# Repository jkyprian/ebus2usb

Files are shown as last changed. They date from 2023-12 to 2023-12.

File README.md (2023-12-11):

# ebus2usb - 1TE DIN Rail eBUS to USB Type-C Interface

eBUS is a serial 2-wire serial data-bus, often used in heating, solar energy, and other building automation systems. This project provides an interface to access an eBUS via USB.
It uses a series transistor regulator circuit with a low IZT zener diode to extract the operating voltage from the eBUS, an ADuM1201 for the galvanic isolation, and a STM32 microcontroller for the UART to USB conversion.
Power consumption on the eBUS side is between 475uA (eBUS low/8V) and 750uA (eBUS idle high/24V), making the interface qualify as a class 0 device with respect to the eBUS specification.
It has been designed to fit into an [CNMB/1/2](https://www.camdenboss.com/camden-boss/cnmb12-din-rail-module-box%2c-polycarbonate-enclosure%2c-industrial-iot-electronics-housing/c-23/p-18541) 1TE DIN rail enclosure by CAMDENBOSS. The interface is intended to be used with [ebusd](https://github.com/john30/ebusd/). Note that the firmware is currently just a proof-of-concept and only implements a basic uart to USB bridge. Support for the ebusd enhanced protocol is planned for the near future.

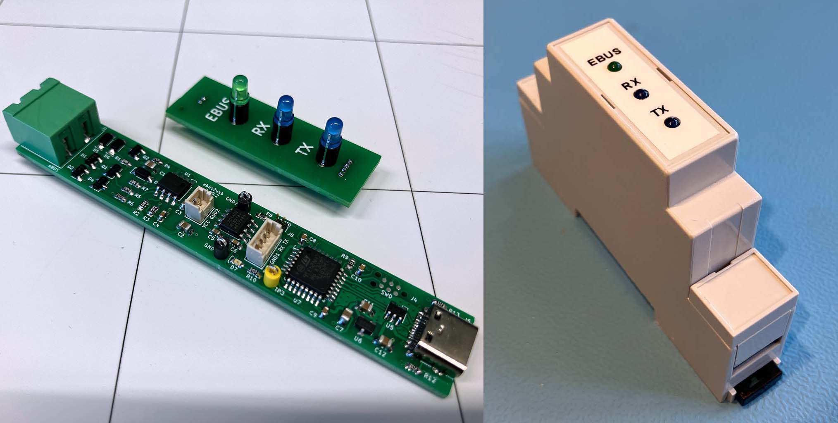
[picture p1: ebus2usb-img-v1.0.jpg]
Images


## Schematic

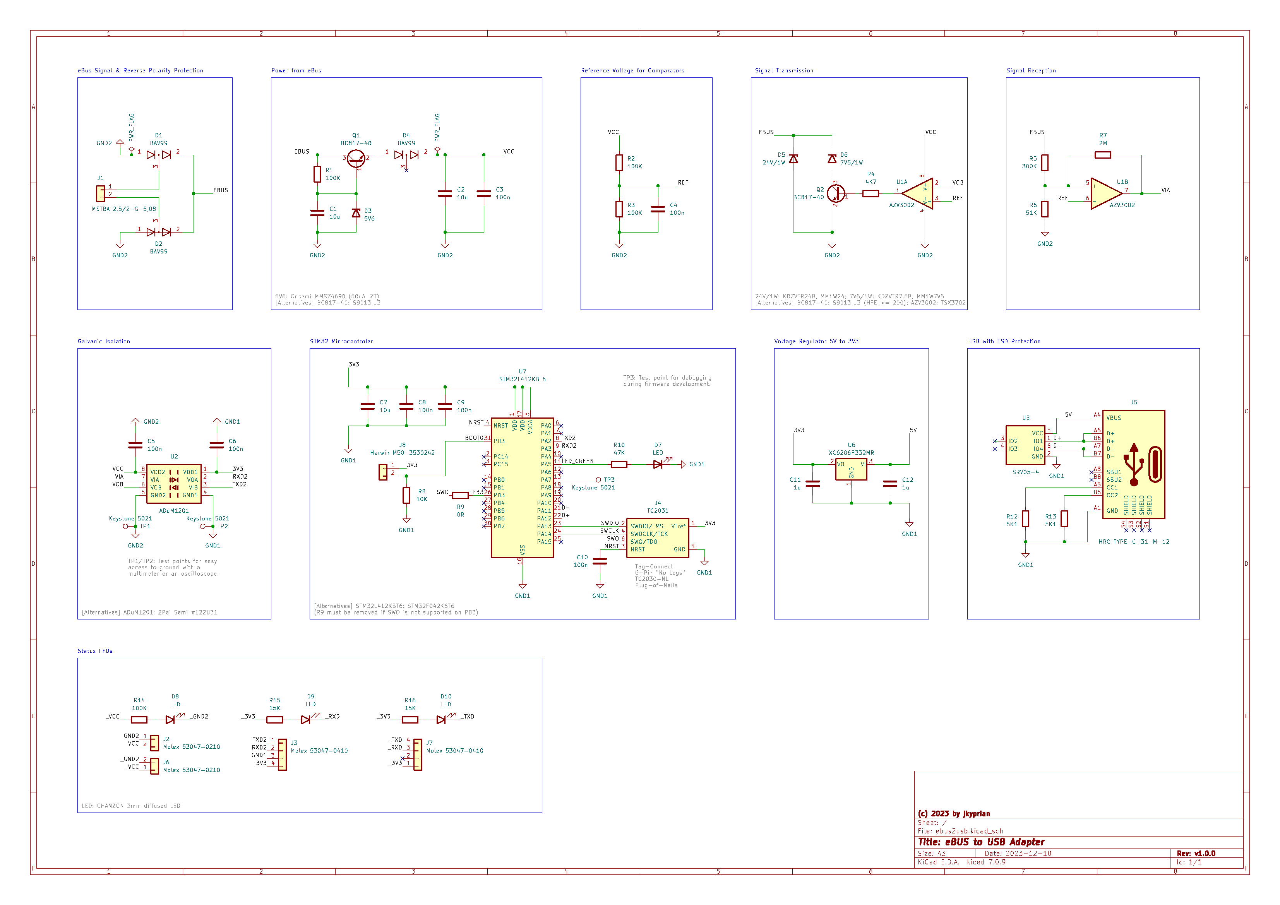
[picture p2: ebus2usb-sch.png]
Schematic


## PCB Layout

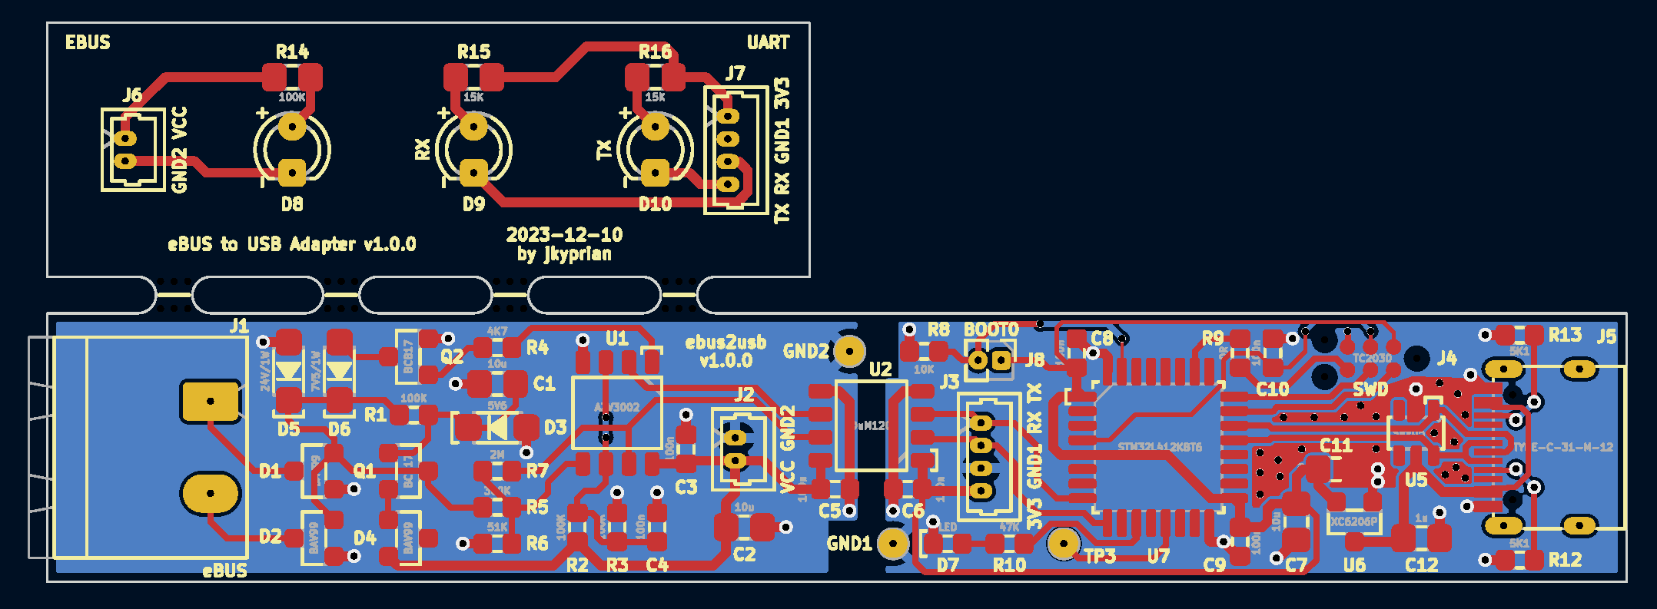
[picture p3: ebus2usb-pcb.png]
PCB Layout


When ordering at JLCPCB, remove the mouse bites and cut the boards yourself. Otherwise JLCPCB will charge you for two designs.

## BOM

|Designator|Footprint|Quantity|Value|LCSC Part #
|:---|:---|:---|:---|:---
|C1, C2, C7|C0805|3|10u|C15850
|C10, C3, C4, C5, C6, C8, C9|C0603|7|100n|C14663
|C11, C12|C0805|2|1u|C28323
|D1, D2, D4|SOT-23-3|3|BAV99|C2500
|D3|SOD-123|1|5V6, Onsemi MMSZ4690*|C152307
|D5|SOD-123|1|24V/1W, KDZVTR24B, MM1W24|C209605, C438336
|D6|SOD-123|1|7V5/1W, KDZVTR7.5B, MM1W7V5|C209594, C382950
|D7|LED_0603|1|LED|C72043
|D8, D9, D10|D3.0mm|3|3mm LED|[CHANZON 3mm diffused LED](https://www.aliexpress.com/item/1936229691.html)
|J1|MSTBA_2,5_2-G-5,08|1|MSTBA 2,5/2-G-5,08|C3697
|J2, J6|Molex_PicoBlade_53047-0210|2|Molex 53047-0210|C114130
|J3, J7|Molex_PicoBlade_53047-0410|2|Molex 53047-0410|C504989
|J4|TC2030-NL|1|Tag-Connect 6-Pin \"No Legs\" TC2030-NL Plug-of-Nails|[TC2030-CTX-NL-STDC14](https://www.tag-connect.com/product/tc2030-ctx-nl-stdc14-for-use-with-stm32-processors-with-stlink-v3)
|J5|HRO_TYPE-C-31-M-12|1|HRO TYPE-C-31-M-12|C165948
|J8|PinHeader_1x02_P1.27mm|1|Harwin M50-3530242|C2881948
|Q1, Q2|SOT-23-3|2|BC817-40, S9013J3|C52801, C6749
|R1, R2, R3|R0603|3|100K|C25803
|R10|R0603|1|47K|C25819
|R12, R13|R0603|2|5K1|C23186
|R14|R0805|1|100K|C149504
|R15, R16|R0805|2|15K|C17475
|R4|R0603|1|4K7|C23162
|R5|R0603|1|300K|C23024
|R6|R0603|1|51K|C23196
|R7|R0603|1|2M|C22976
|R8|R0603|1|10K|C25804
|R9|R0603|1|0R|C21189
|U1|SO08|1|AZV3002, TSX3702|C5123396, C2970396
|U2|SO08|1|ADuM1201, π122U31|C9669, C471590
|U5|SOT-23-6L|1|SRV05-4|C85364
|U6|SOT-23-3|1|XC6206P332MR|C5446
|U7|LQFP-32|1|STM32L412KBT6, STM32F042K6T6|C529438, C69216

\* Low IZT of 50uA is required. Other manufacturers than Onsemi may not qualify. For example, MMSZ4690 from Jiangsu Changjing Elec. Tech. is not recommened.

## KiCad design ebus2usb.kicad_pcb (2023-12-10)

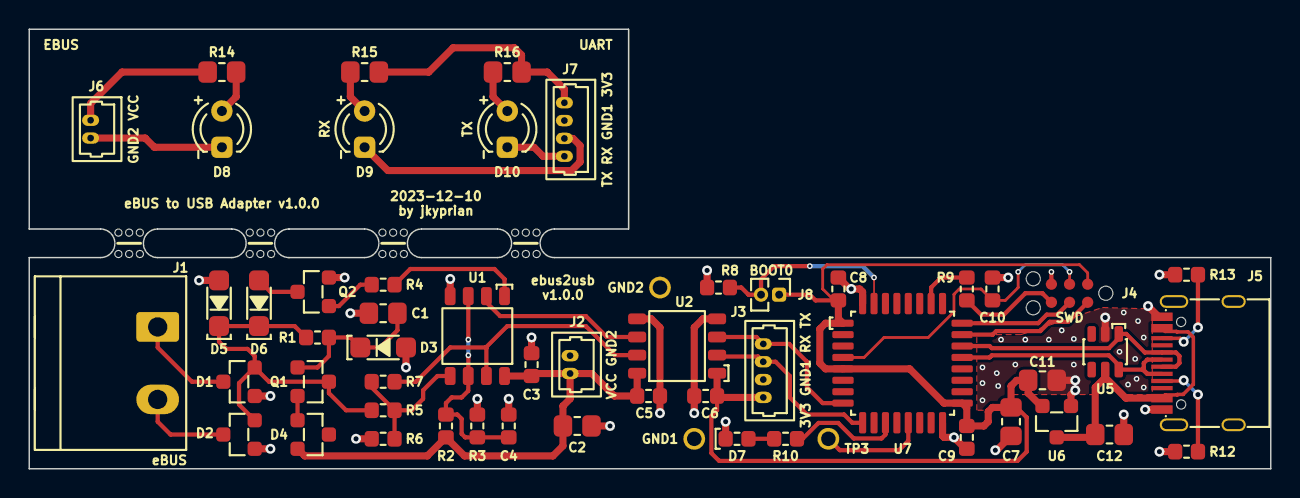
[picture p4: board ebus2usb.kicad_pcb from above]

Board: 2 copper layers, 87.0 x 30.8 mm, 59 parts (0 on the bottom side), 40 nets.

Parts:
C1, C2, C7: 10u; C0805
C3, C4, C5, C6, C8, C9, C10: 100n; C0603
C11, C12: 1u; C0805
D1, D2, D4: BAV99; SOT-23-3
D3: 5V6; SOD-123
D5: 24V/1W; SOD-123
D6: 7V5/1W; SOD-123
D7: LED; LED_0603
D8, D9, D10: LED; LED_D3.0mm
J1: MSTBA 2,5/2-G-5,08; MSTBA_2,5_2-G-5,08
J2, J6: Molex 53047-0210; Molex_PicoBlade_53047-0210
J3, J7: Molex 53047-0410; Molex_PicoBlade_53047-0410
J4: TC2030; TC-2030NL
J5: HRO TYPE-C-31-M-12; HRO_TYPE-C-31-M-12
J8: Harwin M50-3530242; PinHeader_1x02_P1.27mm
Q1, Q2: BC817-40; SOT-23-3
R1, R2, R3: 100K; R0603
R4: 4K7; R0603
R5: 300K; R0603
R6: 51K; R0603
R7: 2M; R0603
R8: 10K; R0603
R9: 0R; R0603
R10: 47K; R0603
R12, R13: 5K1; R0603
R14: 100K; R0805
R15, R16: 15K; R0805
TP1, TP2, TP3: Keystone 5021; Keystone_5021
U1: AZV3002; SO08
U2: ADuM1201; SO08
U5: SRV05-4; SOT-23-6L
U6: XC6206P332MR; SOT-23-3
U7: STM32L412KBT6; LQFP-32
mouse-bite-2mm-slot, mouse-bite-2mm-slot#2, mouse-bite-2mm-slot#3, mouse-bite-2mm-slot#4: VAL**; mouse-bite-2mm-slot

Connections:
/3V3: C6.2, C7.1, C8.1, C9.1, C11.1, J3.4, J4.1 (VTref), J8.1, U2.1 (VDD1), U6.2 (VO), U7.1 (VDD), U7.5 (VDDA), U7.17 (VDD)
/5V: C12.1, J5.A4 (VBUS), J5.A9 (VBUS), J5.B4 (VBUS), J5.B9 (VBUS), U5.5 (VCC), U6.3 (VI)
/BOOT0: J8.2, R8.2, U7.31 (PH3)
/D+: J5.A6 (D+), J5.B6 (D+), U5.1 (IO1), U7.22 (PA12)
/D-: J5.A7 (D-), J5.B7 (D-), U5.6 (IO4), U7.21 (PA11)
/EBUS: D1.2 (A), D2.2 (A), D5.1 (K), D6.1 (K), Q1.3 (C), R1.2, R5.2
/LED_GREEN: R10.2, U7.11 (PA5)
/NRST: C10.1, J4.3 (NRST), U7.4 (NRST)
/PB3: R9.1, U7.26 (PB3)
/REF: C4.1, R2.1, R3.2, U1.3 (+), U1.6 (-)
/RXD2: J3.2, U2.2 (VOA), U7.9 (PA3)
/SWCLK: J4.4 (SWDCLK/TCK), U7.24 (PA14)
/SWDIO: J4.2 (SWDIO/TMS), U7.23 (PA13)
/SWO: J4.6 (SWO/TDO), R9.2
/TXD2: J3.1, U2.3 (VIB), U7.8 (PA2)
/VCC: C2.1, C3.1, C5.2, D4.2 (A), J2.2, R2.2, U1.8 (V+), U2.8 (VDD2)
/VIA: R7.2, U1.7, U2.7 (VIA)
/VOB: U1.2 (-), U2.6 (VOB)
/_3V3: J7.1, R15.2, R16.2
/_GND2: D8.1 (K), J6.2
/_RXD: D9.1 (K), J7.3
/_TXD: D10.1 (K), J7.4
/_VCC: J6.1, R14.2
GND1: C6.1, C7.2, C8.2, C9.2, C10.2, C11.2, C12.2, D7.1 (K), J3.3, J4.5 (GND), J5.A1 (GND), J5.A12 (GND), J5.B1 (GND), J5.B12 (GND), R8.1, R12.1, R13.1, TP2.1, U2.4 (GND1), U5.2 (GND), U6.1 (GND), U7.16 (VSS), U7.32 (VSS)
GND2: C1.2, C2.2, C3.2, C4.2, C5.1, D1.1 (K), D2.1 (K), D3.2 (A), D5.2 (A), J2.1, Q2.2 (E), R3.1, R6.1, TP1.1, U1.4 (V-), U2.5 (GND2)
unnamed: C1.1, D3.1 (K), Q1.1 (B), R1.1
unnamed: D6.2 (A), Q2.3 (C)
unnamed: D7.2 (A), R10.1
unnamed: D8.2 (A), R14.1
unnamed: D9.2 (A), R15.1
unnamed: D10.2 (A), R16.1
unnamed: D1.3 (K), J1.1
unnamed: D2.3 (K), J1.2
unnamed: J5.A5 (CC1), R12.2
unnamed: J5.B5 (CC2), R13.2
unnamed: D4.1 (K), Q1.2 (E)
unnamed: Q2.1 (B), R4.1
unnamed: R4.2, U1.1
unnamed: R5.1, R6.2, R7.1, U1.5 (+)
unnamed: TP3.1, U7.13 (PA7)

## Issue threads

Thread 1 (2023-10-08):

JLCPCB: D6,D7,D8,TP1,TP2 designators don't exist in the BOM file

Breina, 2023-10-08:
Forgive me asking stupid questions. I understand D6, D7 and D8 are LED's that I will solder myself, but TP1 and TP2 don't seem to appear anywhere. Should they be removed from `positions.csv`?

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

jkyprian, 2023-10-08:
T1 and T2 are just test points for GND2 and GND1 and can be ignored.
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
They are convenient to hook up ground of an oscilloscope or multimeter.
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

Closed 2023-10-08.

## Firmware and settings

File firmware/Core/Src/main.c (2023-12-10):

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
/* Includes ------------------------------------------------------------------*/
#include "main.h"
#include "usb_device.h"

/* USER CODE BEGIN Includes */
#include "usbd_cdc_if.h"
/* USER CODE END Includes */


/* USER CODE BEGIN PV */
int rx_head = 0;
int rx_tail = 0;
uint8_t RX_BUF[64];
int tx_head = 0;
int tx_tail = 0;
uint8_t TX_BUF[64];
/* USER CODE END PV */

void SystemClock_Config(void);
static void MX_GPIO_Init(void);
static void MX_USART2_UART_Init(void);
/**
  * @brief  The application entry point.
  * @retval int
  */
int main(void)
{
  /* MCU Configuration--------------------------------------------------------*/

  /* Reset of all peripherals, Initializes the Flash interface and the Systick. */
  HAL_Init();

  /* Configure the system clock */
  SystemClock_Config();

  /* Initialize all configured peripherals */
  MX_GPIO_Init();
  MX_USART2_UART_Init();
  MX_USB_DEVICE_Init();
  /* Infinite loop */
  /* USER CODE BEGIN WHILE */
  HAL_GPIO_WritePin(LED_GPIO_Port, LED_Pin, GPIO_PIN_SET);
  while (1)
  {
    //HAL_GPIO_TogglePin(LED_GPIO_Port, LEDPin);
    if (LL_USART_IsActiveFlag_ORE(USART2)) {
      LL_USART_ClearFlag_ORE(USART2);
    }
    if (LL_USART_IsActiveFlag_RXNE(USART2)) {
      RX_BUF[rx_head] = LL_USART_ReceiveData8(USART2);
      rx_head = (rx_head + 1) & 0x3F;
    }
    if (LL_USART_IsActiveFlag_TXE(USART2) && (tx_tail != tx_head)) {
      LL_USART_ClearFlag_TC(USART2);
      LL_USART_TransmitData8(USART2, TX_BUF[tx_tail]);
      tx_tail = (tx_tail + 1) & 0x3F;
    }

    if (rx_tail != rx_head) {
      if (CDC_Transmit_FS(&RX_BUF[rx_tail], 1) == USBD_OK) {
            rx_tail = (rx_tail + 1) & 0x3F;
      }
    }
    /* USER CODE END WHILE */

    /* USER CODE BEGIN 3 */
  }
  /* USER CODE END 3 */
}

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


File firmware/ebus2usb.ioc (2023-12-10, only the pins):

Mcu.UserName=STM32L412KBTx
PA11.Signal=USB_DM
PA12.Signal=USB_DP
PA2.Signal=USART2_TX
PA3.Signal=USART2_RX
PA5.GPIO_Label=LED
PA5.Signal=GPIO_Output
PA7.GPIO_Label=TP3
PA7.Signal=GPIO_Output

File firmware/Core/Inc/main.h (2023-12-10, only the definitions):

#define LED_Pin LL_GPIO_PIN_5
#define LED_GPIO_Port GPIOA
#define TP3_Pin LL_GPIO_PIN_7
#define TP3_GPIO_Port GPIOA

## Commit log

2023-05-15 v0.8.1 * Size of main board changed to 87mm x 14.8mm * R5 changed from 1K5 to 4K7 * TS3702/TCL3702 replaced by TSX3702 (need VCC on one input)
    [bom.csv, ebus2usb.kicad_pcb, ebus2usb.kicad_sch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]
2023-07-08 * Replaced voltage reference with low IZT 5V6 zener diode (cheaper but increases power consumption on the eBus side by ~200uA) * C2/C4 changed to 10u * R6/R7 adjusted for ~5V VCC * AZV3002 as replace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
    [bom.csv, designators.csv, ebus2usb.kicad_pcb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]
2023-12-10 New version with STM32 microcontroller.
    [bom.csv, designators.csv, ebus2usb.kicad_pcb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]
2023-12-11 Added info for TC2030-NL to schematic and BOM
    [ebus2usb.kicad_sch]

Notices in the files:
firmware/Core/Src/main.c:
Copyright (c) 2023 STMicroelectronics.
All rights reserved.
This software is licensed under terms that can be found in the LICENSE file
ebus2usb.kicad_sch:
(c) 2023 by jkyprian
